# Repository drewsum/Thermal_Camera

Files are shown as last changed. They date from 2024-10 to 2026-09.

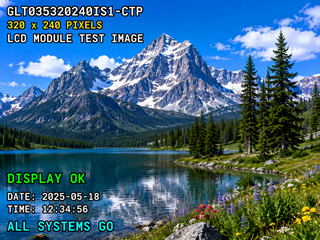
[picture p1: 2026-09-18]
rev_a/sfw/LCD_Test_Images/LCD_test_mountain.png

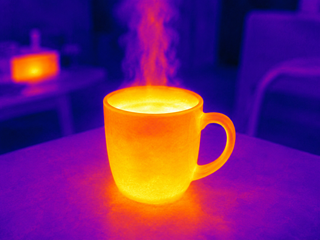
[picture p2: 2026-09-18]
rev_a/sfw/LCD_Test_Images/thermal_coffee.png

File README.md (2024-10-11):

# Thermal_Camera
DIY Thermal Camera - Drew Maatman and Michael Laffin

## Hardware:
### KiCad Project:
\Thermal_Camera\rev_a\hdw\Thermal_Camera
Made in KiCad version 8.0.5
PIC32MZ DA Grphics MCU
FLIR Lepton 3.5 Thermal Imagery Sensor
PIC32MZ DA is programmed with firmware via PICKIT4 Header (J1501)
PIC32MZ DA can be held in reset by pressing SW1501 or by inserting jumper across J1502
USB Hub can be reset by pressing SW2501
SPI FLASH can be programmed via J2002

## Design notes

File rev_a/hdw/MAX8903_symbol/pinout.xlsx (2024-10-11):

MAX8903
Pin | Name | Unit | Type | Style | Side
1 | PG | A | power_in |  | bottom
2 | PG | A | power_in |  | bottom
3 | DC | A | power_in |  | left
4 | DC | A | power_in |  | left
5 | DCM | A | input |  | left
6 | BST | A | passive |  | left
7 | IUSB | A | passive |  | left
8 | ~{DOK} | A | output | output_low | right
9 | VL | A | passive |  | right
10 | CT | A | passive |  | left
11 | IDC | A | passive |  | right
12 | GND | A | power_in |  | bottom
13 | ISET | A | passive |  | right
14 | ~{CEN} | A | input | input_low | left
15 | USUS | A | input |  | left
16 | THM | A | passive |  | right
17 | USB | A | power_in |  | left
18 | ~{FLT} | A | output | output_low | right
19 | ~{UOK} | A | output | output_low | right
20 | BAT | A | power_in |  | right
21 | BAT | A | power_in |  | right
22 | ~{CHG} | A | output | output_low | right
23 | SYS | A | power_out |  | right
24 | SYS | A | passive |  | right
25 | CS | A | passive |  | left
26 | CS | A | passive |  | left
27 | LX | A | passive |  | left
28 | LX | A | passive |  | left
29 | EP | A | power_in |  | bottom

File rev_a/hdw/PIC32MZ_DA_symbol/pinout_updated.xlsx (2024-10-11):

PIC32MZ2064DAR176
Pin | Name | Unit | Type | Style | Side
3 | AVDD | A | power_in |  | left
4 | AVDD | A | power_in |  | left
5 | AVSS | A | power_in |  | left
6 | AVSS | A | power_in |  | left
66 | DDRVREF | A | power_in |  | left
166 | VBAT | A | power_in |  | left
18 | VDDCORE | A | power_in |  | left
39 | VDDCORE | A | power_in |  | left
84 | VDDCORE | A | power_in |  | left
116 | VDDCORE | A | power_in |  | left
19 | VDDIO | A | power_in |  | left
38 | VDDIO | A | power_in |  | left
86 | VDDIO | A | power_in |  | left
102 | VDDIO | A | power_in |  | left
117 | VDDIO | A | power_in |  | left
124 | VDDIO | A | power_in |  | left
155 | VDDIO | A | power_in |  | left
156 | VDDIO | A | power_in |  | left
165 | VDDIO | A | power_in |  | left
57 | VDDR1V8 | A | power_in |  | left
58 | VDDR1V8 | A | power_in |  | left
59 | VDDR1V8 | A | power_in |  | left
60 | VDDR1V8 | A | power_in |  | left
61 | VDDR1V8 | A | power_in |  | left
62 | VDDR1V8 | A | power_in |  | left
63 | VDDR1V8 | A | power_in |  | left
67 | VDDR1V8 | A | power_in |  | left
68 | VDDR1V8 | A | power_in |  | left
72 | VDDR1V8 | A | power_in |  | left
78 | VDDR1V8 | A | power_in |  | left
21 | VSS | A | power_in |  | right
22 | VSS | A | power_in |  | right
29 | VSS | A | power_in |  | right
37 | VSS | A | power_in |  | right
48 | VSS | A | power_in |  | right
49 | VSS | A | power_in |  | right
83 | VSS | A | power_in |  | right
87 | VSS | A | power_in |  | right
94 | VSS | A | power_in |  | right
103 | VSS | A | power_in |  | right
115 | VSS | A | power_in |  | right
122 | VSS | A | power_in |  | right
123 | VSS | A | power_in |  | right
153 | VSS | A | power_in |  | right
154 | VSS | A | power_in |  | right
177 | VSS1P8 | A | power_in |  | right
44 | No Connect | A | no_connect |  | right
88 | No Connect | A | no_connect |  | right
20 | No Connect | A | no_connect |  | right
176 | No Connect | A | no_connect |  | right
85 | MCLR | A | input |  | right
45 | VBUS | A | power_in |  | right
46 | VUSB3V3 | A | power_out |  | right
47 | VUSB3V3 | A | passive |  | right
51 | D+ | A | bidirectional |  | right
50 | D- | A | bidirectional |  | right
52 | USBID | A | passive |  | right
53 | TMS/SDCD/RA0 | B | bidirectional |  | left
160 | TCK/AN24/RA1 | B | bidirectional |  | left
129 | SCL2/RA2 | B | bidirectional |  | left
128 | EBIRDY1/SDA2/RA3 | B | bidirectional |  | left
127 | GD1/EBID14/PMD14/RA4 | B | bidirectional |  | left
174 | EBIA5/AN7/PMA5/RA5 | B | bidirectional |  | left
54 | TRCLK/SDCK/SQICLK/RA6 | B | bidirectional |  | left
55 | TRD3/SDDATA3/SQID3/RA7 | B | bidirectional |  | left
1 | VREF-/CVREF-/AN27/RA9 | B | bidirectional |  | left
2 | VREF+/CVREF+/AN28/RA10 | B | bidirectional |  | left
126 | RPA14/SCL1/RA14 | B | bidirectional |  | left
125 | RPA15/SDA1/RA15 | B | bidirectional |  | left
168 | PGED1/AN0/RPB0/CTED2/RB0 | B | bidirectional |  | left
11 | PGEC1/AN9/RPB1/CTED1/RB1 | B | bidirectional |  | left
172 | AN1/C2INB/RPB2/RB2 | B | bidirectional |  | left
8 | AN8/RPB3/RB3 | B | bidirectional |  | left
175 | AN2/C1INB/RB4 | B | bidirectional |  | left
167 | AN45/RPB5/RB5 | B | bidirectional |  | left
13 | PGEC2/RPB6/RB6 | B | bidirectional |  | left
170 | PGED2/C1INA/AN46/RPB7/RB7 | B | bidirectional |  | left
10 | EBID10/AN4/RPB8/PMD10/RB8 | B | bidirectional |  | left
173 | EBIA7/AN47/HLVDIN/RPB9/PMA7/RB9 | B | bidirectional |  | left
168 | AN5/RPB10/RB10 | B | bidirectional |  | left
12 | AN49/RB11 | B | bidirectional |  | left
171 | AN6/RB12 | B | bidirectional |  | left
9 | AN48/CTPLS/RB13 | B | bidirectional |  | left
159 | AN29/SCK3/RB14 | B | bidirectional |  | left
7 | AN3/C2INA/RPB15/OCFB/RB15 | B | bidirectional |  | left
17 | EBID5/AN12/RPC1/PMD5/RC1 | B | bidirectional |  | right
14 | EBID12/AN10/RPC2/PMD12/RC2 | B | bidirectional |  | right
15 | EBIWE/AN34/RPC3/PMWR/RC3 | B | bidirectional |  | right
16 | EBIOE/AN19/RPC4/PMRD/RC4 | B | bidirectional |  | right
164 | OSC1/CLKI/RC12 | B | bidirectional |  | right
162 | SOSCI/RPC13/RC13 | B | bidirectional |  | right
161 | SOSCO/RPC14/T1CK/RC14 | B | bidirectional |  | right
163 | OSC2/CLKO/RC15 | B | bidirectional |  | right
79 | RTCC/RPD0/RD0 | B | bidirectional |  | right
73 | SCK1/RD1 | B | bidirectional |  | right
74 | GD10/EBIA14/RPD2/PMA14/PMCS1/RD2 | B | bidirectional |  | right
75 | GD11/EBIA15/RPD3/PMA15/PMCS2/RD3 | B | bidirectional |  | right
70 | SDCMD/SQICS0/RPD4/RD4 | B | bidirectional |  | right
71 | SQICS1/RPD5/RD5 | B | bidirectional |  | right
121 | ETXEN/RPD6/RD6 | B | bidirectional |  | right
120 | ETXCLK/RPD7/RD7 | B | bidirectional |  | right
76 | GD2/EBID15/RPD9/PMD15/RD9 | B | bidirectional |  | right
77 | SCK4/RD10 | B | bidirectional |  | right
119 | EMDC/RPD11/RD11 | B | bidirectional |  | right
80 | GD7/EBIA12/RPD12/PMA12/RD12 | B | bidirectional |  | right
81 | GD22/EBIA13/PMA13/RD13 | B | bidirectional |  | right
158 | AN22/RPD14/RD14 | B | bidirectional |  | right
157 | AN33/SCK6/RD15 | B | bidirectional |  | right
40 | EBID0/PMD0/RE0 | B | bidirectional |  | right
36 | EBID1/AN39/PMD1/RE1 | B | bidirectional |  | right
99 | EBID2/PMD2/RE2 | B | bidirectional |  | right
98 | EBID3/RPE3/PMD3/RE3 | B | bidirectional |  | right
43 | EBID4/AN18/PMD4/RE4 | B | bidirectional |  | right
69 | EBIA6/RPE5/PMA6/RE5 | B | bidirectional |  | right
23 | EBID6/AN16/PMD6/RE6 | B | bidirectional |  | right
24 | EBID7/AN15/PMD7/RE7 | B | bidirectional |  | right
25 | AN25/RPE8/RE8 | B | bidirectional |  | right
26 | AN26/RPE9/RE9 | B | bidirectional |  | right
91 | GD6/EBIA11/RPF0/PMA11/RF0 | C | bidirectional |  | left
90 | GD5/EBIA10/RPF1/PMA10/RF1 | C | bidirectional |  | left
41 | RPF2/SDA3/RF2 | C | bidirectional |  | left
93 | ERXERR/RPF3/RF3 | C | bidirectional |  | left
97 | GD17/EBID9/RPF4/SDA5/PMD9/RF4 | C | bidirectional |  | left
89 | GD16/EBID8/RPF5/SCL5/PMD8/RF5 | C | bidirectional |  | left
82 | RPF8/SCL3/RF8 | C | bidirectional |  | left
27 | TDO/AN31/RPF12/RF12 | C | bidirectional |  | left
28 | TDI/AN17/SCK5/RF13 | C | bidirectional |  | left
96 | GD3/EBIA8/RPG0/PMA8/RG0 | C | bidirectional |  | left
95 | GD4/EBIA9/RPG1/PMA9/RG1 | C | bidirectional |  | left
30 | AN14/C1IND/SCK2/RG6 | C | bidirectional |  | left
31 | AN13/C1INC/RPG7/SDA4/RG7 | C | bidirectional |  | left
32 | AN30/C2IND/RPG8/SCL4/RG8 | C | bidirectional |  | left
33 | EBIA2/AN23/C2INC/RPG9/PMA2/RG9 | C | bidirectional |  | left
56 | TRD1/SDDATA1/SQID1/RG12 | C | bidirectional |  | left
64 | TRD0/SDDATA0/SQID0/RG13 | C | bidirectional |  | left
65 | TRD2/SDDATA2/SQID2/RG14 | C | bidirectional |  | left
34 | AN21/RG15 | C | bidirectional |  | left
110 | ETXD2/RH0 | C | bidirectional |  | left
109 | ETXD3/RH1 | C | bidirectional |  | left
141 | SDWP/EBIRP/RH2 | C | bidirectional |  | left
140 | AN35/RH3 | C | bidirectional |  | left
35 | AN20/RH4 | C | bidirectional |  | left
100 | ERXD1/RH5 | C | bidirectional |  | left
101 | ERXD2/RH6 | C | bidirectional |  | left
139 | EBIA4/AN36/PMA4/RH7 | C | bidirectional |  | left
108 | ERXD0/RH8 | C | bidirectional |  | left
107 | ERXD3/RH9 | C | bidirectional |  | left
106 | ECOL/RH10 | C | bidirectional |  | left
138 | EBIRDY2/AN37/RH11 | C | bidirectional |  | left
105 | ECRS/RH12 | C | bidirectional |  | left
104 | ERXDV/ECRSDV/RH13 | C | bidirectional |  | left
42 | INT0/RH14 | C | bidirectional |  | left
92 | GD21/EBIA23/RH15 | C | bidirectional |  | left
118 | ETXERR/RJ0 | C | bidirectional |  | right
114 | EMDIO/RJ1 | C | bidirectional |  | right
152 | EBIRDY3/AN32/RJ2 | C | bidirectional |  | right
151 | GD20/EBIA22/RJ3 | C | bidirectional |  | right
150 | VSYNC/EBICS0/RJ4 | C | bidirectional |  | right
149 | HSYNC/EBICS1/RJ5 | C | bidirectional |  | right
148 | GCLK/EBICS2/RJ6 | C | bidirectional |  | right
147 | GEN/EBICS3/RJ7 | C | bidirectional |  | right
113 | ETXD0/RJ8 | C | bidirectional |  | right
112 | ETXD1/RJ9 | C | bidirectional |  | right
146 | GD18/EBIBS1/RJ10 | C | bidirectional |  | right
111 | ERXCLK/EREFCLK/RJ11 | C | bidirectional |  | right
145 | GD9/EBIBS0/RJ12 | C | bidirectional |  | right
144 | GD0/EBID13/PMD13/RJ13 | C | bidirectional |  | right
143 | GD8/EBID11/PMD11/RJ14 | C | bidirectional |  | right
142 | EBIA0/PMA0/RJ15 | C | bidirectional |  | right
137 | GD23/EBIA16/RK0 | C | bidirectional |  | right
136 | EBIA1/AN38/PMA1/RK1 | C | bidirectional |  | right
135 | EBIA3/AN11/PMA3/RK2 | C | bidirectional |  | right
134 | GD12/EBIA17/RK3 | C | bidirectional |  | right
133 | GD13/EBIA18/RK4 | C | bidirectional |  | right
132 | GD14/EBIA19/RK5 | C | bidirectional |  | right
131 | GD15/EBIA20/RK6 | C | bidirectional |  | right
130 | GD19/EBIA21/RK7 | C | bidirectional |  | right

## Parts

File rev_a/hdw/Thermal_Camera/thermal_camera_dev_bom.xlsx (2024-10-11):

Reference | Value | Qty | Configuration | Digi-Key PN | display_footprint
BT1401 | 18650 Cell | 1 |  | 1568-1488-ND
C201,C405,C605,C1707,C1708,C1709,C1710,C1711,C1712,C1720,C1721,C1722,C1723,C1724,C1725,C1733,C1734,C1735,C1736,C1737,C1738,C1745,C1746,C1747,C1748,C1749,C1750,C1756,C1757,C1758,C1759,C1760,C1762,C1764,C2901,C2902,C3101,C3102,C3103,C3104,C3105,C3106,C3107,C3108,C3109,C3110,C3111,C3112,C3113,C3114,C3115,C3116,C3117,C3118,C3119,C3120,C3121,C3122,C3123,C3124,C3125,C3126,C3127,C3128,C3129,C3130,C3131,C3132,C3133 | 10nF | 69 |  | 445-12201-1-ND | 402
C202,C401,C406,C601,C606,C803,C1001,C1004,C1405,C1407,C1414,C1501,C1502,C1601,C1602,C1603,C1701,C1702,C1703,C1704,C1705,C1706,C1713,C1714,C1715,C1716,C1717,C1718,C1727,C1728,C1729,C1730,C1731,C1732,C1739,C1740,C1741,C1742,C1743,C1744,C1751,C1752,C1753,C1754,C1755,C1761,C1763,C2001,C2003,C2006,C2101,C2103,C2201,C2202,C2203,C2204,C2207,C2210,C2401,C2403,C2404,C2405,C2501,C2502,C2503,C2504,C2506,C2507,C2509,C2602,C2701,C2702,C2703,C2704,C2705,C2706,C2707,C2708,C2709,C2801,C2802,C2803,C2804,C2903,C2904,C2907,C2908 | 0.1uF | 87 |  | 490-10697-1-ND | 402
C203 | 100uF | 1 |  | 718-1102-1-ND | 7343
C301,C302,C303,C501,C502,C503,C701,C702,C703,C901,C902,C903,C1101,C1102,C1103,C1301,C1302,C1303,C2305 | 0.1uF | 19 | Telemetry | 490-10697-1-ND | 402
C402,C404,C407,C408,C602,C604,C607,C608,C1201,C1203,C1204,C1402,C1404,C1409,C1410,C1412,C1413,C1765,C1766,C2102,C2104,C2607 | 10uF | 22 |  | 399-8153-1-ND | 1206
C403,C603,C801,C802,C804,C805,C1002,C1003,C1005,C1006,C1403,C1406,C1604,C1605,C2002,C2004,C2005,C2007,C2205,C2206,C2211,C2402,C2505,C2508,C2601,C2603,C2605,C2905,C2906 | 10uF | 29 |  | 490-GRM155R61A106ME11DCT-ND | 402
C1202,C1401,C1408,C1411 | 1uF | 4 |  | 311-1439-1-ND | 402
C1719,C1726,C2208,C2209 | 47pF | 4 |  | 490-5942-1-ND | 402
C2301,C2302,C2303 | 10uF | 3 | ETC | 490-GRM155R61A106ME11DCT-ND | 402
C2304 | 0.1uF | 1 | ETC | 490-10697-1-ND | 402
C2604,C2606 | 22pF | 2 |  | 490-5868-1-ND | 402
D401,D601 | BAT48JFILM | 2 |  | 497-5711-1-ND
D1201 | PMEG6010CEJ | 1 |  | 1727-3882-1-ND
D1501 | PESD3V3L5UY | 1 |  | 1727-3828-1-ND
D2001,D2002 | PESD3V3L4UF | 2 |  | 1727-5789-1-ND
D2201 | Yellow | 1 |  | VLMY1500-GS08CT-ND
D2301 | BAT48JFILM | 1 | ETC | 497-5711-1-ND
D2701,D2702,D2704,D2705,D2706,D2707,D2709,D2801 | Green | 8 |  | 1497-1219-1-ND
D2703,D2708,D2802,D2803,D2804 | Red | 5 |  | VLMS1500-GS08CT-ND
J1401 | 18650 Holder | 1 |  | BK-18650-PC2-ND
J2001 | Micro_SD_Card_Det_Hirose_DM3AT | 1 |  | HR1964CT-ND
J2101 | LCD Pixel Data | 1 |  | 2073-FFC2B35-54-GCT-ND
J2102 | LCD CTP Data | 1 |  | 2073-FFC2B35-06-GCT-ND
J2601 | USB_B_Mini | 1 |  | 732-2109-1-ND
L401,L601 | 2.2uH | 2 |  | 541-1236-1-ND | IHLP2020
L1201 | 22uH | 1 |  | 541-1243-1-ND | IHLP2020
L1401 | 4.7uH | 1 |  | 541-1222-1-ND | IHLP2020
L1501,L1502,L1601,L1602,L1701,L1702,L2401,L2501 | 600R 0.5A | 8 |  | 490-5441-1-ND
N201 | +12V 1A Power Supply | 1 |  | 993-1335-ND
N2101 | LCD Module | 1 |  | GLT035320240IS1-CTP
N2401 | Lepton3.5 Sensor | 1 |  | 500-0771-01-ND
Q401,Q601,Q1501 | BSS214NW | 3 |  | BSS214NWH6327XTSA1CT-ND
Q402,Q602 | ZXMS6004FFTA | 2 |  | ZXMS6004FFCT-ND
Q1401,Q1402 | DMN3042L | 2 |  | DMN3042L-7DICT-ND
R201 | 51.1k | 1 |  | RMCF0402FT51K1CT-ND | 402
R202,R209,R409,R807,R2605 | 1.15k | 5 |  | RMCF0402FT1K15CT-ND | 402
R203,R208 | 5.11k | 2 |  | RMCF0402FT5K11CT-ND | 402
R204,R206,R211,R402,R403,R404,R602,R603,R604,R801,R802,R1001,R1002,R1003,R1201,R1407,R1410,R1502,R1504,R1601,R1602,R1603,R1604,R1801,R1802,R2011,R2012,R2013,R2014,R2015,R2016,R2017,R2018,R2019,R2020,R2021,R2022,R2023,R2024,R2029,R2101,R2102,R2103,R2104,R2202,R2401,R2402,R2403,R2404,R2405,R2406,R2407,R2408,R2409,R2502,R2503,R2504,R2505,R2506,R2507,R2601,R2701,R2801,R2802,R2805,R2806,R2905,R2906,R2907,R2908,R2909,R2910 | 10k | 72 |  | RMCF0402FT10K0CT-ND | 402
R205,R210,R405,R407,R605,R607,R803,R805,R1004,R1006,R1204,R1206 | 10 | 12 | Telemetry | RMCF0402FT10R0CT-ND | 402
R207,R406,R606,R804,R1005,R1205,R1412,R1413 | 0.02 | 8 |  | P16010CT-ND | 612
R401,R601,R1202,R1203,R1501,R1503,R1605,R1606,R2001,R2002,R2003,R2004,R2005,R2006,R2025,R2026,R2027,R2028,R2030,R2410,R2411,R2412,R2413,R2414,R2415,R2501 | 10 | 26 |  | RMCF0402FT10R0CT-ND | 402
R408 | 3.16k | 1 |  | RMCF0402FT3K16CT-ND | 402
R608 | 1.87k | 1 |  | RMCF0402FT1K87CT-ND | 402
R609,R2606 | 1.5k | 2 |  | RMCF0402FT1K50CT-ND | 402
R806 | 2.87k | 1 |  | RMCF0402FT2K87CT-ND | 402
R1007,R1406 | 5.9k | 2 |  | RMCF0402FT5K90CT-ND | 402
R1008 | 11.8k | 1 |  | RMCF0402FT11K8CT-ND | 402
R1401,R1403 | 10K | 2 |  | RMCF0402FT10K0CT-ND | 402
R1402 | 1.8M | 1 |  | RMCF0402FT1M80CT-ND | 402
R1404,R1405,R1408,R1409 | 100k | 4 |  | RMCF0402FT100KCT-ND | 402
R1411 | 1.2k | 1 |  | RMCF0402FT1K20CT-ND | 402
R1414 | 2.2k | 1 |  | RMCF0402FT2K20CT-ND | 402
R1415 | 330 | 1 |  | RMCF0402FT330RCT-ND | 402
R1505,R2201,R2702,R2703,R2704,R2705,R2706,R2707,R2708,R2709,R2710,R2803,R2804,R2807,R2808,R2901,R2902,R2903,R2904 | 1k | 19 |  | RMCF0402FT1K00CT-ND | 402
R1701,R1702,R2203,R2204,R2602,R2603 | 27 | 6 |  | RMCF0402FT27R0CT-ND | 402
R1703,R1704,R2205,R2206 | 15k | 4 |  | RMCF0402FT15K0CT-ND | 402
R2604 | 3.57k | 1 |  | RMCF0402FT3K57CT-ND | 402
RN2101,RN2102,RN2103,RN2104 | 10k | 4 |  | Y1103CT-ND
TH1401,TH1402 | 10k | 2 |  | 445-174911-1-ND | 402
TP202,TP203,TP401,TP601,TP801,TP1001,TP1601,TP2601,TP2602 | TP | 9
U201 | TPS26600RHFT | 1 |  | 296-45478-1-ND
U301,U501,U701,U901,U1101,U1301 | INA231A | 6 | Telemetry | 296-41263-1-ND
U302,U502,U702,U902,U1102,U1302,U2302 | MCP9804 | 7 | Telemetry | MCP9804T-E/MCCT-ND
U401,U601,U1001,U1601,U2202,U2501,U2503,U2701,U2702,U2703,U2704,U2705,U2706,U2707,U2801,U2802,U2803,U2804,U2903,U2904 | 74LVC1G97 | 20 |  | 296-15582-1-ND
U402,U602 | TPS62130A | 2 |  | 296-39446-1-ND
U801,U1002,U2601 | TPS7A92 | 3 |  | TPS7A9201DSKR
U1201 | DIO5661CD6 | 1 |  | N/A
U1401 | BQ27441DRZT-G1A | 1 |  | 296-37271-1-ND
U1402 | MAX8903G | 1 |  | MAX8903GETI+-ND
U1403 | BQ29700 | 1 |  | 296-43985-1-ND
U1701 | PIC32MZ2064DAR176 | 1 |  | PIC32MZ2064DAR176-I/2J-ND
U2001 | SST25VF080B-50-4x-S2Ax | 1 |  | SST25VF080B-50-4C-S2AF-ND
U2002 | TPS22810DRV | 1 |  | 296-47868-1-ND
U2201 | FT234XD | 1 |  | 768-1178-1-ND
U2203 | FXMA108 | 1 |  | FXMA108BQX
U2301 | DS1683 | 1 | ETC | DS1683S+-ND
U2401 | FLIR_Lepton3p5_Socket | 1 |  | 1050281001
U2502 | TPS3808G33 | 1 |  | 296-17195-1-ND
U2504 | TUSB2046BIRHBT | 1 |  | 296-27130-1-ND
U2602 | TPD3S044DBVR | 1 |  | 296-38836-1-ND
U2708,U2709 | 74LVC1G97 | 2 |  | 296-15582-1-ND
U2901,U2902 | AT42QT1010-TSHR | 2 |  | AT42QT1010-TSHRCT-ND
X1601 | ECS-2520MV-240-BN | 1 |  | XC2750CT-ND
X1602 | ECS-327KE | 1 |  | XC1751CT-ND
X2401 | ECS-2520MV-250-CN | 1 |  | XC2752CT-ND
X2501 | ASE-48.000MHz | 1 |  | 535-ASE-48.000MHZ-L-C-TCT-ND

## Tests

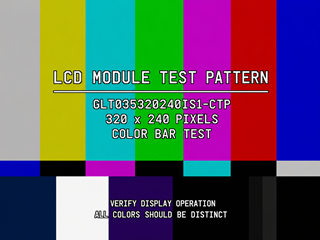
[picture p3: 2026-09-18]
rev_a/sfw/LCD_Test_Images/LCD_test.png

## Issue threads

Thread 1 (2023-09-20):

Sensor

drewsum, 2023-09-20:
https://www.digikey.com/en/products/detail/flir-lepton/500-0771-01/7606616

drewsum, 2023-09-20:
https://www.flir.com/globalassets/imported-assets/document/flir-lepton-engineering-datasheet.pdf

drewsum, 2023-09-20:
Socket: https://www.digikey.com/en/products/detail/molex/1050281001/3045223

Closed 2024-10-11.

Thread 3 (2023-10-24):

Input power + battery management

mslaffin, 2023-10-24:
### Requirements
- Accept power from several inputs
    - USB, 12V wall adapter, Li-ion battery
    - Battery probably something standard (4.2V?)
- Outputs regulated system power
- Indicate battery charge status, output supply good
- configurable to the selected battery

Some features I think are cool
-  reporting state of charge, faults, temp, etc.
- integrated buck converters
- fancy charging algos
- efficiency

Here's a few options:

[MAX8903](https://www.analog.com/media/en/technical-documentation/data-sheets/MAX8903-MAX8903Y.pdf) – Basic features shared with many parts, seems like it would work. Doesn’t require external FETs/diodes

[LTC4089-3](https://www.analog.com/media/en/technical-documentation/data-sheets/40893fa.pdf) – more configurable and could also work. More part selection. Maybe overkill.

[BQ24180](https://www.ti.com/lit/ds/symlink/bq24180.pdf?ts=1698112114656&ref_url=https%253A%252F%252Fwww.google.com%252F) - Also integrated power FETs, I2C interface

Some relevant things that need to be determined:
- [ ] #5
- [ ] #4
    - charge current
    - float voltage

Closed 2024-10-11.

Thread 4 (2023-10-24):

battery selection

mslaffin, 2023-10-24:
Some things to think about:

- Power management devices mostly limited to single cells
    - the BQ24180 also refers to "battery pack", but this may only refer to Li-polymer?
- Common characteristics for single cells
    -  3.7V nominal voltage
    - 4.2V full charge
- capacity
    - probably not more than 1-2 Ah needed
- discharge current
    - [ ] system power requirements
- integrated protection
- form factor
    - I like how DSLR-type cameras put the battery in the grip. also gun-style infrared thermometers do a similar thing
- connector type

Closed 2024-10-11.

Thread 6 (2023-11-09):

MCU selection

drewsum, 2023-11-09:
- PIC32MZ EF:
  - Pros:
    - Drew extremely familiar with this
    - Lots of code overlap with existing projects
    - Lots of pin count and memory options
    - KiCad symbols ready to go
    - Hand solderable packages
    - The compiler and IDE are awesome, no need to bit shift to control registers
    - Easy debug
    - Extremely flexible interrupts
  - Cons:
    - Memory for graphics is limited
    - No built in LCD controller (would need to leverage other peripherals not meant for this)
    - Unsure how USB would work (I just normally use a UART to USB bridge)
    - No built in SD card controller
    - MPLAB Harmony code framework is garbage (could generate peripheral drivers and copy to bare metal project)
- PIC32MZ DA:
  - Pros:
    - Meant for graphics applications
    - More internal SRAM available than 32MZ EF
    - Built in LCD controller
    - Built in on-die 32MB DDR2
    - Certain options support 128MB external DDR2
    - Very similar to PIC32MZ EF
    - Built in SD card controller
    - The compiler and IDE are awesome, no need to bit shift to control registers
    - Apparently there is a GUI for configuring the graphics capabilities
    - Available in hand solderable packages, also BGA
    - Dedicated GPU
    - Easy debug
    - Extremely flexible interrupts
    - Its cool af
  - Cons:
    - New part to both of us
    - Some code overlap with 32MZ EF, might be able to branch off easily though, but this would require lots of new code
    - Would need new KiCad symbols
    - Would need lots of support circuit design thought/analysis/critical thinking, not just copy and paste
    - Unsure how useful the graphics configuration applications actually are, they could be hot steaming garbage and we'd be on our own
- STM32:
  - Pros:
    - It's a thing that exists and apparently the support is good
    - I have seen that they have some kind of graphics support
  - Cons:
    - I have no idea how to use these
- ESP32 S3:

drewsum, 2023-11-10:
I had chatted with Michael a bunch about this, and the PIC32MZ DA seems like a good fit. This will require a lot of investment in code and hardware development, but since it's meant for video, it seems like a good idea.

There are a few different flavors of PIC32MZ DA, but the more modern SKUs from circa 2019 have a datasheet here: https://ww1.microchip.com/downloads/aemDocuments/documents/MCU32/ProductDocuments/DataSheets/PIC32MZ-Graphics-%28DAK-DAL-DAR-DAS%29-Family-Datasheet-DS60001565D.pdf

They offer them in BGA and LQFP packages in high pin counts. I looked into the BGA package in KiCad briefly and it looks like the ball pitch is barely too tight to make work with JLCPCB design rules. I think it would be easier to use the LQFP package, but would take up much more space.

Looking at the SKUs for this package, these are available:
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

I think the PIC32MZ2064DAR176 is most realistic. The high internal SRAM is nice, as is the internal 32MB DDR2, which we'd use as a frame buffer for the LCD. We could also try to get fancy with microchip's GUI generation tools.

This is enough of a departure from my current projects to make this interesting and require engineering and firmware rigor, but is close enough where a lot of code could be ported over easily.

PIC32MZ2064DAR176  appears to be available in ok-ish quantities according to octopart. If we design a PCB around this, the good news is that there are other options that are drop in replacements, just with different memory sizes. So I think that the part selection is actually quite flexible.

Closed 2024-10-11.

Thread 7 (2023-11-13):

Consider +3.0V supply instead of +3.3V supply

drewsum, 2023-11-13:
PIC32MZ DA supports a +3.0V VDDIO, and the FLIR lepton is limited to +3.0V IO. Consider consolidating these instead of having two supplies

drewsum, 2023-11-14:
I don't think we'll be able to swing this based on just how much on this board already needs +3.3V... most LCDs I'm seeing need +3.3V, the oscillators I'm already comfortable with are +3.3V only, USH hub, etc. So I'm going to close this for now

drewsum, 2023-11-15:
Things that would need to move from +3.3V to +3.0V in order to make this work:

- PIC IO (doable)
- Telemetry circuits (INA219 has min VIN +3.0V, MCP9804 ok)
- TPS62130 does not come in a fixed +3.0V option, could use feedback resistors
- Check to see if PIC KIT 4 is compatible with +3.0V
- PIC oscillators (current part is +3.3V only, oscillator I found for FLIR sensor is +3.0V compatible)
- SD card
- SPI Flash
- SQI Flash
- LCD (most options I'm seeing out there are +3.3V only)
- USB UART level shifter/voltage domain isolator
- DS1683 (this should be ok)
- All LVC logic gates (should be ok, maybe move to AUP family?)

There is a lot here, but it's not impossible. I think the main deciding factor is if we can find a usable +3.0V IO-compatible TFT LCD screen.

According to the SD card spec, you can power micro SD cards with as low as 2.7V: https://www.sdcard.org/developers/sd-standard-overview/

drewsum, 2023-11-18:
I decided that based on what I've seen for LCDs, and the availability of parts that are indeed +3.0V VDD tolerant, we should do this.

Closed 2024-10-11.

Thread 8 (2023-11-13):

Consider USB hub for multiple USB upstream facing ports

drewsum, 2023-11-13:

drewsum, 2023-11-15:
The idea here would be to use a USB 2 port hub to break out both the USB UART debug port and the USB HS mass storage port (what would allow us to easily move captured thermal images to a host PC) through a single USB connector. The hub would enumerate as a generic hub and expose both the FTDI UART device and the PIC32MZ DA HS USB port like any other device.

The idea would be that the hub IC would be powered by VBUS, and could remain unpowered when a USB connector is not connected (I think?). There may be complications with this due to DC leakage paths from the PIC to the unpowered hub IC.

An alternative would be to just use two USB connectors, which I'm also ok with

Closed 2024-10-11.

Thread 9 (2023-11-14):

User Interface Ideas

drewsum, 2023-11-14:
- Try to support cap touch screen on LCD for extended options
- Have a capacitive pushbutton for power button, and "save frame", as a minimum fallback

Closed 2024-10-11.

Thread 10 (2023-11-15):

LCD

drewsum, 2023-11-15:
https://www.digikey.com/en/products/detail/globaltech-display/GLT035320240IS1-CTP/16588709

drewsum, 2023-11-15:
- Needs to support at least the resolution of the Lepton3.5 sensor (i dont remember what this is)
- Would be nice to match the aspect ratio of the sensor but not required since we can scale the video frames
- Would be nice to have it a decent size but not huge
- Cap touch screen maybe? Lets talk about user interface in another gitlab issue, i have ideas
- Should match one of the IO types that the PIC32MZ DA GLCD controller can output, I'm unsure of the options but it should be captured in the datasheet, also see the PIC32 GLCD "reference manual" doc (WVGA? idk what any of these are or what they mean)
- RGB888 data format (PIC32 GLCD controller does 24 bit color)
- Match IO voltage level of PIC (+3.3V or +3.0V)
- Preferably not super expensive

drewsum, 2023-11-16:
This seems like a thing a person could use to drive the LED backlight to an LCD, it seems to be made to run off a lithium battery, it's super small, looks like it supports PWM dimming (although I've had mixed luck with these kinds of claims in the past), and has a symbol in KiCad laready

https://www.analog.com/media/en/technical-documentation/data-sheets/3465fa.pdf

drewsum, 2023-11-21:
> https://www.digikey.com/en/products/detail/globaltech-display/GLT035320240IS1-CTP/16588709

This went out of stock and doesnt seem to have much availability anywhere else.

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

drewsum, 2024-07-18:
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

Back in stock, and this FFC connector could probably work:
https://www.digikey.com/en/products/detail/kyocera-avx/046240054005800/1279146

Closed 2024-10-11.

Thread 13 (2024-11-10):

Rev A ECOs

drewsum, 2024-11-10:
- POS3P0_RUN is hardwired to POS12_PGOOD. If POS12 is not present, POS3P0 will not be up. This means that when switching to battery power, POS3P0 will not stay up. For now, remove R401 and modwire POS3P0 to VCOM

drewsum, 2024-11-15:
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

USB 15k D+/D- pulldowns were placed on the wrong side of the 27 ohm resistors

drewsum, 2024-12-06:
USB hub issues:
Try:

- Cutting RTS/CTS signals from FTDI to octal buffer
- removing filter caps on D+/D- at FTDI

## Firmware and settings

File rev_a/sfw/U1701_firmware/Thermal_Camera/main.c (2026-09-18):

/* 
 * File:   main.c
 * Author: drewm
 *
 */

#include <xc.h>
#include <stdio.h>
#include <stdbool.h>
#include <string.h>

// Core Drivers
#include "core/pic32mzda_configuration.h"
#include "core/device_control.h"
#include "core/32mzda_interrupt_control.h"
#include "core/heartbeat_timer.h"
#include "core/watchdog_timer.h"
#include "core/prefetch.h"
#include "core/cause_of_reset.h"
#include "core/rtcc.h"
#include "core/hlvd.h"
#include "core/ddr2.h"

// SPI
#include "spi/spi3.h"
#include "spi/device_driver/w25q128jv.h"
#include "spi/device_driver/w25q128jv_disk.h"
#include "spi/flash_fileio.h"

// SDHC / microSD
#include "sdhc/sdhc.h"
#include "sdhc/device_driver/sd_card.h"
#include "sdhc/sd_fileio.h"

// USB (mass storage device)
#include "usb/usb.h"
#include "usb/device_driver/usb_msd.h"

// GLCD
#include "glcd/glcd.h"

// GUI (LVGL on GLCD Layer 1)
#include "gui/gui.h"

// FLIR Lepton 3.5 thermal camera (VoSPI on SPI4, CCI on I2C1)
#include "application/flir/flir.h"
#include "application/flir/flir_vospi.h"
#include "application/flir/flir_process.h"

// GPIO
#include "gpio/pin_macros.h"
#include "gpio/pic32mzda_gpio_setup.h"


//
//// Application
#include "application/error_handler.h"
#include "application/main.h"
#include "application/power_saving.h"
#include "application/heartbeat_services.h"
#include "application/telemetry.h"
#include "application/pgood_monitor.h"
#include "application/pushbuttons.h"
#include "application/backlight_pwm.h"
#include "application/image_loader.h"
#include "application/still_capture.h"


////// I2C
#include "i2c/i2c_master.h"
#include "i2c/i2c_devices.h"
//// USB UART
#include "usb_uart/terminal_control.h"
#include "usb_uart/uthash.h"
#include "usb_uart/usb_uart.h"
#include "usb_uart/usb_uart_rx_lookup_table.h"
//
////// ADC
#include "adc/adc.h"
#include "application/adc_channels.h"


// Prints a boot initialization result line and records failures. On success it
// prints "    <label> Initialized" in green; on failure it prints
// "    <label> FAILED to initialize" in bold red and sets *error_flag (pass
// NULL for subsystems with no dedicated init flag). Returns ok unchanged so it
// can wrap an init call inline. Leaves the terminal in green/normal afterward.
static bool reportInit(const char *label, bool ok, volatile uint8_t *error_flag) {

    if (ok) {

        terminalTextAttributes(GREEN_COLOR, BLACK_COLOR, NORMAL_FONT);
        printf("    %s Initialized\r\n", label);

    }

    else {

        if (error_flag != NULL) *error_flag = 1;
        terminalTextAttributes(RED_COLOR, BLACK_COLOR, BOLD_FONT);
        printf("    %s FAILED to initialize\r\n", label);
        terminalTextAttributes(GREEN_COLOR, BLACK_COLOR, NORMAL_FONT);

    }

    return ok;

}

void main(void) {

    
    // Save the cause of the most recent device reset
    // This also checks for configuration errors
    reset_cause = getResetCause();
    
    // Clear the terminal
    terminalClearScreen();
    terminalSetCursorHome();
    
    // set serial terminal window name
    char *terminal_title_str;
    terminal_title_str = (char *) malloc(64);
    sprintf(terminal_title_str, "%s Serial Terminal", PROJECT_NAME_STR);
    terminalSetTitle(terminal_title_str);
    free(terminal_title_str);
    
    terminalTextAttributesReset();
    terminalTextAttributes(GREEN_COLOR, BLACK_COLOR, BOLD_FONT);
    printf("%s\r\n", PROJECT_NAME_STR);
    printf("Host Firmware Version: %s, Platform Hardware Revision: %s\r\n", FIRMWARE_VERSION_STR, PLATFORM_REVISION_STR);
    printf("Created by Drew Maatman, %s\r\n", PROJECT_DATE_STR);
    
    printf("\r\n");
    
    printf(""
    "\r\n"        
    "  _____ _                               _    ____                               \r\n"
    " |_   _| |__   ___ _ __ _ __ ___   __ _| |  / ___|__ _ _ __ ___   ___ _ __ __ _ \r\n"
    "   | | | '_ \\ / _ \\ '__| '_ ` _ \\ / _` | | | |   / _` | '_ ` _ \\ / _ \\ '__/ _` |\r\n"
    "   | | | | | |  __/ |  | | | | | | (_| | | | |__| (_| | | | | | |  __/ | | (_| |\r\n"
    "   |_| |_| |_|\\___|_|  |_| |_| |_|\\__,_|_|  \\____\\__,_|_| |_| |_|\\___|_|  \\__,_|\r\n"
    "               \r\n");

    terminalTextAttributesReset();
    
     // Print cause of reset
    if (    reset_cause == Undefined ||
            reset_cause == Primary_Config_Registers_Error ||
            reset_cause == Primary_Secondary_Config_Registers_Error ||
            reset_cause == Config_Mismatch ||
            reset_cause == DMT_Reset ||
            reset_cause == WDT_Reset ||
            reset_cause == Software_Reset ||
            reset_cause == External_Reset ||
            reset_cause == BOR_Reset ||
            reset_cause == VBAT_POR) {

        terminalTextAttributes(RED_COLOR, BLACK_COLOR, NORMAL_FONT);

    }

    else {

        // Deep_Sleep_Reset and VBAT_Wake are expected outcomes of the
        // low-power features this device is configured for, not faults
        terminalTextAttributes(GREEN_COLOR, BLACK_COLOR, NORMAL_FONT);

    }

    // Deep Sleep exit, VBAT wake, and VBAT POR all re-arm a POR at the
    // hardware level (RAM/SFRs reset the same as a plain POR), so persistent
    // error flags are just as unreliable after these as after a plain POR
    if (    reset_cause == POR_Reset ||
            reset_cause == Deep_Sleep_Reset ||
            reset_cause == VBAT_Wake ||
            reset_cause == VBAT_POR) {
        clearErrorHandler();
        live_telemetry_enable = 0;
    }

    errorHandlerInitialize();

    // live_telemetry_print_request is not persistent, so always clear it at boot
    live_telemetry_print_request = 0;

    printf("\r\nCause of most recent device reset: %s\r\n\r\n", getResetCauseString(reset_cause));
    terminalTextAttributesReset();
    
    terminalTextAttributes(GREEN_COLOR, BLACK_COLOR, BOLD_FONT);
    printf("Beginning Host Initialization:\r\n");
    terminalTextAttributes(GREEN_COLOR, BLACK_COLOR, NORMAL_FONT);
    
     // setup GPIO pins
    reportInit("GPIO Pins", gpioInitialize(), NULL);

    // block on POS3P0 and POS1P8 power stability
    while(POS3P0_PGOOD_PIN == LOW);
    while(POS1P8_PGOOD_PIN == LOW);
    printf("    Input power is stable\r\n");
    
    // Disable global interrupts so clocks can be initialized properly
    disableGlobalInterrupts();
    
    // Initialize system clocks
    reportInit("Oscillators, PLL, and System Clocks", clockInitialize(),
            &error_handler.flags.clock_init_error);
        
    // Enable Global Interrupts
    bool interrupts_ok = interruptControllerInitialize();
    enableGlobalInterrupts();
    reportInit("Interrupt Controller", interrupts_ok, NULL);
    
    // Setup error handling
    reportInit("Error Handler", errorHandlerInitialize(), NULL);

    // Setup Power/Shutter pushbutton change-notification interrupts
    reportInit("Pushbuttons", pushbuttonsInitialize(), NULL);

    // Setup heartbeat timer
    reportInit("Heartbeat Timer", heartbeatTimerInitialize(),
            &error_handler.flags.heartbeat_timer_init_error);
        
    // Setup USB UART debugging
    reportInit("USB UART", usbUartInitialize(),
            &error_handler.flags.usb_uart_init_error);
    
    // Setup prefetch module
    reportInit("CPU Instruction Prefetch Module", prefetchInitialize(),
            &error_handler.flags.prefetch_init_error);
    while(usbUartCheckIfBusy());
    
    // Disable unused peripherals for power savings
    reportInit("Peripheral Module Disable (PMD)", PMDInitialize(),
            &error_handler.flags.pmd_init_error);
    while(usbUartCheckIfBusy());

    // setup watchdog timer
    reportInit("Watchdog Timer", watchdogTimerInitialize(),
            &error_handler.flags.watchdog_init_error);
    while(usbUartCheckIfBusy());
    
    // ---- Splash-screen fast path ------------------------------------------
    // Everything from here to the backlight enable below is exactly the
    // dependency chain the splash needs, and nothing else: DDR2 (frame
    // buffers + LVGL heap), the SPI flash and its FAT volume (where
    // SPLASH.PNG lives), the GLCD and its Layer 2, the backlight, LVGL
    // (whose heap lodepng decodes into), and the I2C bus master -- the last
    // of these only because lighting the backlight is now conditional on the
    // GT911 touch controller answering, i.e. on the panel being populated.
    // The bus master is register setup only; the one real cost is the GT911
    // probe itself (~70ms of datasheet-mandated reset timing), which is
    // documented at the call site.
    //
    // The RTCC, ADC, I2C *device* probe, SDHC controller and USB device
    // stack all used to run in here; none of them is needed to put a picture
    // on the panel, and together with their console output they were pushing
    // the splash several hundred milliseconds later than necessary. They now
    // run immediately AFTER the splash is lit -- see "deferred bring-up"
    // below. Anything added here in future should be able to justify itself
    // as a splash dependency.

    // Power the FLIR Lepton up BEFORE the I2C bus is touched. This is not
    // optional: with its +2.8V/+1.2V rails down, the unpowered module clamps
    // SDA/SCL low through its I/O structures and every other device on I2C1
    // (temp sensors, power monitors, fuel gauge, touch controller) becomes
    // unreachable. So the sensor is powered for the whole run -- only the
    // video stream is on demand ("FLIR Stream On").
    //
    // This call is the fast part of the sequence (rails -> PGOOD -> master
    // clock -> release power-down -> release reset); the camera's ~950ms boot
    // then overlaps everything below and is collected by FLIR_WaitUntilReady()
    // once I2C and the display are up. Failures latch flir_* error flags.
    reportInit("FLIR Lepton Power", FLIR_PowerOn(), NULL);
    while(usbUartCheckIfBusy());

    // Initialize the 32MB DDR2 SDRAM stacked in this device's package
    reportInit("DDR2 SDRAM Controller", ddr2Initialize(),
            &error_handler.flags.ddr2_init_error);
    while(usbUartCheckIfBusy());

    // Initialize the W25Q128JV SPI NOR flash on SPI3
    reportInit("SPI Flash (W25Q128JV)", W25Q128JV_Initialize(),
            &error_handler.flags.spi_flash_init_error);
    while(usbUartCheckIfBusy());

    // FAT volume "1:" on the SPI flash (512B-sector disk layer over the
    // 4KB-erase part, then mount -- formats on first boot, so the
    // "formatting..." notice is expected exactly once per blank part).
    // SPLASH.PNG is read from this volume, so it is on the fast path.
    reportInit("SPI Flash Filesystem",
            W25Q128JV_Disk_Initialize() && FlashFileIO_MountAndFormatIfNeeded(),
            &error_handler.flags.flash_fs_init_error);
    while(usbUartCheckIfBusy());

    // Bring up the Graphics LCD Controller for the on-board
    // GLT035320240IS1-CTP panel: programs timing/Layer 0 from a blank
    // (zeroed) frame buffer in DDR2 and drives the panel reset sequence.
    // The frame buffer is intentionally left blank -- filling it with
    // actual image data is a separate step. Must come after ddr2Initialize()
    // above (the frame buffer lives in DDR2).
    reportInit("Graphics LCD Controller", GLCD_Initialize(),
            &error_handler.flags.glcd_init_error);
    while(usbUartCheckIfBusy());

    // GLCD Layer 2 (on-demand still-image layer): brought up as early as the
    // hardware allows -- right after GLCD_Initialize(), ahead of the GUI and
    // the Lepton -- so the splash screen below can go up before either of
    // those slower subsystems is ready. Only needs the controller running
    // (glcd.c checks LCDEN itself); it does NOT need GUI_Initialize(), which
    // is why this sits here rather than next to ImageLoader_DisplayPNG().
    reportInit("GLCD Layer 2 (still image)", GLCD_Layer2Initialize(), NULL);
    while(usbUartCheckIfBusy());

    // Backlight brightness is PWM-driven (OC3/Timer4, application/backlight_pwm.c)
    // rather than a plain digital enable pin -- must be initialized after
    // clockInitialize() above (which sets CFGCON.OCACLK=1 under unlock,
    // establishing the OC3-to-Timer4 pairing this driver verifies at init;
    // see backlight_pwm.h for the full story).
    reportInit("Backlight PWM", BacklightPWM_Initialize(),
            &error_handler.flags.backlight_pwm_init_error);
    while(usbUartCheckIfBusy());

    // setup I2C -- still after FLIR_PowerOn() above, which is the constraint
    // that actually matters (an unpowered Lepton clamps SDA/SCL low).
    //
    // This is on the splash fast path only because the backlight is now
    // gated on the GT911 touch controller answering (see the CTP probe
    // below): the bus master has to be up before that probe can run. It is
    // just register setup -- no bus traffic, no measurable time -- so it
    // costs the splash nothing. The 15-device probe it used to be paired
    // with stays deferred, down in "deferred bring-up".
    reportInit("I2C Bus Master", I2C_Initialize(),
            &error_handler.flags.i2c_init_error);
    while(usbUartCheckIfBusy());

    // Bring up LVGL on GLCD Layer 1: a transparent GUI overlay the
    // controller alpha-blends over the Layer 0 image. Must come after
    // GLCD_Initialize() (it enables a layer on the running controller) and
    // after ddr2Initialize() (its two overlay buffers and its 4MB heap are
    // all in DDR2). That heap also backs every PNG decode
    // (application/image_loader.c), so this has to run before the
    // "Display Image:" command can be used.
    reportInit("Graphics User Interface", GUI_Initialize(),
            &error_handler.flags.gui_init_error);
    while(usbUartCheckIfBusy());

    // Display the splash screen now: Layer 2 has been enabled since right
    // after GLCD_Initialize() above, and this is the earliest point the PNG
    // decode itself can run, since it allocates from the LVGL heap that
    // GUI_Initialize() just handed out (application/image_loader.h). Layer 2
    // is fully opaque and painted on top of Layer 0/1, so it hides the (still
    // booting) Lepton and the just-built GUI screens until the splash timer
    // below dismisses it.
    ImageLoader_DisplayPNG(IMAGE_MEDIA_SPI_FLASH, "SPLASH.PNG");

    // Light the panel THE MOMENT the splash is in the frame buffer, and not
    // one line of init sooner or later.
    //
    // BacklightPWM_Initialize() above only programs the OC3/Timer4 PWM; it
    // leaves the duty cycle at 0, i.e. the backlight physically OFF. This
    // SetBrightness() call used to sit after the whole FLIR bring-up and the
    // SD card mount, so the panel stayed dark for that entire stretch even
    // though the splash pixels had been sitting in the Layer 2 buffer the
    // whole time -- and once FLIR_WaitUntilReady() grew a multi-second poll
    // window (application/flir/flir.c), a camera that was slow to answer
    // held the screen black for seconds. THAT was the "splash takes ages to
    // appear" delay; the panel was lit last instead of first.
    //
    // Everything below this line is therefore invisible to the user: the
    // splash is already up and covering Layer 0/1 while it runs.
    //
    // The backlight is gated on the panel's integrated GT911 capacitive
    // touch controller answering on I2C: its ACK is a reliable proxy for
    // "the LCD module is actually populated on this board", which the GLCD
    // Controller itself cannot detect (it only configures MCU-internal
    // registers, so it comes up perfectly happy driving nothing).
    //
    // The probe is the ONE thing allowed to delay the splash: it costs
    // ~70ms, almost all of it the GT911's mandated power-up reset/
    // address-select timing (10ms + 5ms + 50ms of pin toggling, see
    // i2c/device_driver/gt911.h), which cannot be shortened. That buys the
    // panel-presence check; the alternative was gating on the full 15-device
    // probe several hundred milliseconds further down. The rest of that
    // probe stays deferred -- only the CTP is pulled forward here, and
    // I2CDevices_Initialize() below re-probes it harmlessly along with
    // everything else.
    //
    // No error_handler flag is passed to reportInit(): like the "I2C Devices"
    // probe below, I2CDevices_InitializeOne() has already latched this
    // device's OWN flag (I2C_DEV_CTP_1_i2c_error or _config_error, generated
    // from I2C_DEVICE_LIST -- see error_handler.h), which is more specific
    // than any single aggregate flag would be.
    if (reportInit("LCD Touch Controller (GT911)",
            I2CDevices_InitializeOne(I2C_DEV_CTP_1), NULL)) {
        BacklightPWM_SetBrightness(100);
        terminalTextAttributes(GREEN_COLOR, BLACK_COLOR, NORMAL_FONT);
        printf("    LCD Backlight Enabled (touch controller present)\r\n");
    } else {
        terminalTextAttributes(RED_COLOR, BLACK_COLOR, NORMAL_FONT);
        printf("    LCD Backlight left OFF (touch controller not detected)\r\n");
    }
    terminalTextAttributesReset();
    while(usbUartCheckIfBusy());

    // Non-blocking splash-screen dismiss timer, checked once per superloop
    // pass (see splash_screen_pending below) instead of a blocking
    // softwareDelay() (core/device_control.c -- a raw NOP-counting loop with
    // no time calibration), which used to stall I2C/USB/GUI/FLIR servicing
    // for its whole duration. GUI_GetTickMs() (gui/gui.c) is the same
    // monotonic since-boot millisecond source LVGL's own tick already uses,
    // so no second clock is introduced.
    //
    // The clock starts HERE rather than at the top of boot, so the splash
    // gets its full display time no matter how long the deferred bring-up
    // below takes.
    #define SPLASH_SCREEN_DISPLAY_MS   6000u   // tune to taste
    uint32_t splash_screen_shown_tick_ms = GUI_GetTickMs();
    bool splash_screen_pending = true;

    // ---- Deferred bring-up ------------------------------------------------
    // Everything the splash does NOT depend on, moved below it so none of it
    // sits between power-on and a lit panel. Ordering constraints that still
    // apply within this block: the device probe must precede the battery
    // read; SDHC_Initialize() must precede the card mount further down.
    // (I2C_Initialize() used to head this block; it moved up into the fast
    // path when the backlight became conditional on the CTP probe.)

    bool rtcc_ok = rtccInitialize();
    // Deep_Sleep_Reset and VBAT_Wake keep the RTCC running across the event
    // specifically so its time doesn't need to be cleared here -- only clear
    // it when the time was never reliably set (POR) or the backup battery
    // that was supposed to maintain it is missing/depleted (VBAT_POR)
    if (reset_cause == POR_Reset || reset_cause == VBAT_POR) rtccClear();
    reportInit("Real Time Clock-Calendar", rtcc_ok,
            &error_handler.flags.rtcc_init_error);
    while(usbUartCheckIfBusy());

    // Enable ADC
    reportInit("Analog to Digital Converter", ADCInitialize(),
            &error_handler.flags.adc_init_error);
    while(usbUartCheckIfBusy());

    // setup HLVD
    bool hlvd_ok = hlvdInitialize(5, HLVD_DIRECTION_LOW_VOLTAGE);
    while(!hlvdIsReady());
    reportInit("HLVD", hlvd_ok && hlvdIsReady(),
            &error_handler.flags.hlvd_init_error);
    while(usbUartCheckIfBusy());

    // Bring up the SDHC peripheral itself (clocks/interrupt/register
    // defaults only, no card interaction) -- must succeed regardless of
    // whether a card happens to be inserted. Card detection + mount happens
    // later still, after the FLIR bring-up; see that call site.
    reportInit("SDHC Controller", SDHC_Initialize(),
            &error_handler.flags.sdhc_init_error);
    while(usbUartCheckIfBusy());

    // USB mass storage device (native USBHS module to the on-board hub):
    // exposes the SD card (LUN 0) and SPI flash (LUN 1) as two removable
    // drives to a USB host. Requires PMDInitialize() above to have left
    // the USB module enabled.
    reportInit("USB Mass Storage Device", USB_Initialize(),
            &error_handler.flags.usb_msd_init_error);
    while(usbUartCheckIfBusy());

    // probe every device in I2C_DEVICE_LIST (7x MCP9804 temp sensors + 6x
    // INA231A power monitors); I2CDevices_Initialize() records each device's
    // own pass/fail into error_handler.flags.<I2C_DEVICE_ID>_i2c_error (the
    // same flag its runtime reads later latch into on a NACK/timeout), so no
    // single aggregate flag is passed here.
    //
    // Note: with no battery installed this reports failure, because the
    // BQ27441 fuel gauge is powered from the cell -- an expected outcome on
    // a bench board running from USB, not a bus fault.
    reportInit("I2C Devices", I2CDevices_Initialize(), NULL);
    while(usbUartCheckIfBusy());
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

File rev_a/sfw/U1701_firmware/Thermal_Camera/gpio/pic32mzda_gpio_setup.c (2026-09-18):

#include <xc.h>
#include <stdio.h>
#include <string.h>

#include "gpio/pic32mzda_gpio_setup.h"
#include "usb_uart/terminal_control.h"

// initializes port A GPIO pins
void portAGPIOInitialize (void) {
    
    gpioPinSetup(gpio_port_a, 0, TRIS_INPUT, LAT_LOW, ODC_DISABLE, ANALOG_DISABLE);
    gpioPinSetup(gpio_port_a, 1, TRIS_OUTPUT, LAT_LOW, ODC_DISABLE, ANALOG_DISABLE);
    gpioPinSetup(gpio_port_a, 2, TRIS_INPUT, LAT_LOW, ODC_DISABLE, ANALOG_DISABLE);
    gpioPinSetup(gpio_port_a, 3, TRIS_OUTPUT, LAT_LOW, ODC_DISABLE, ANALOG_DISABLE);
    gpioPinSetup(gpio_port_a, 4, TRIS_OUTPUT, LAT_LOW, ODC_DISABLE, ANALOG_DISABLE);
    gpioPinSetup(gpio_port_a, 5, TRIS_OUTPUT, LAT_LOW, ODC_DISABLE, ANALOG_DISABLE);
    gpioPinSetup(gpio_port_a, 6, TRIS_INPUT, LAT_LOW, ODC_DISABLE, ANALOG_DISABLE);
    gpioPinSetup(gpio_port_a, 7, TRIS_INPUT, LAT_LOW, ODC_DISABLE, ANALOG_DISABLE);
    gpioPinSetup(gpio_port_a, 9, TRIS_INPUT, LAT_LOW, ODC_DISABLE, ANALOG_DISABLE);
    gpioPinSetup(gpio_port_a, 10, TRIS_INPUT, LAT_LOW, ODC_DISABLE, ANALOG_DISABLE);
    gpioPinSetup(gpio_port_a, 14, TRIS_INPUT, LAT_LOW, ODC_DISABLE, ANALOG_DISABLE);
    gpioPinSetup(gpio_port_a, 15, TRIS_INPUT, LAT_LOW, ODC_DISABLE, ANALOG_DISABLE);
    
}

// initializes port B GPIO pins
void portBGPIOInitialize (void) {

    gpioPinSetup(gpio_port_b, 0, TRIS_OUTPUT, LAT_LOW, ODC_DISABLE, ANALOG_DISABLE);
    gpioPinSetup(gpio_port_b, 1, TRIS_OUTPUT, LAT_LOW, ODC_DISABLE, ANALOG_DISABLE);
    gpioPinSetup(gpio_port_b, 2, TRIS_OUTPUT, LAT_HIGH, ODC_DISABLE, ANALOG_DISABLE);
    gpioPinSetup(gpio_port_b, 3, TRIS_OUTPUT, LAT_HIGH, ODC_DISABLE, ANALOG_DISABLE);
    RPB3Rbits.RPB3R = U5TX_PPS_OUTPUT;                                                  // Assign RPB3 as U5TX
    gpioPinSetup(gpio_port_b, 4, TRIS_OUTPUT, LAT_HIGH, ODC_DISABLE, ANALOG_DISABLE);
    gpioPinSetup(gpio_port_b, 5, TRIS_OUTPUT, LAT_LOW, ODC_DISABLE, ANALOG_DISABLE);
    RPB5Rbits.RPB5R = OC3_PPS_OUTPUT;                                                   // Assign RPB5 as OC3
    gpioPinSetup(gpio_port_b, 6, TRIS_INPUT, LAT_LOW, ODC_DISABLE, ANALOG_DISABLE);
    U4RXRbits.U4RXR = RPB6_PPS_INPUT;                                                   // Assign RPB6 as U4RX (USB UART receiver)
    gpioPinSetup(gpio_port_b, 7, TRIS_INPUT, LAT_LOW, ODC_DISABLE, ANALOG_DISABLE);
    gpioPinSetup(gpio_port_b, 8, TRIS_INPUT, LAT_LOW, ODC_DISABLE, ANALOG_DISABLE);
    gpioPinSetup(gpio_port_b, 9, TRIS_OUTPUT, LAT_HIGH, ODC_DISABLE, ANALOG_DISABLE);
    RPB9Rbits.RPB9R = SDO3_PPS_OUTPUT;                                                  // Assign RPB9 as SDO3
    gpioPinSetup(gpio_port_b, 10, TRIS_INPUT, LAT_LOW, ODC_DISABLE, ANALOG_DISABLE);
    SDI3Rbits.SDI3R = RPB10_PPS_INPUT;                                                  // Assign RPB10 as SDI3
    gpioPinSetup(gpio_port_b, 11, TRIS_OUTPUT, LAT_LOW, ODC_DISABLE, ANALOG_DISABLE);
    gpioPinSetup(gpio_port_b, 12, TRIS_OUTPUT, LAT_HIGH, ODC_DISABLE, ANALOG_DISABLE);
    gpioPinSetup(gpio_port_b, 13, TRIS_OUTPUT, LAT_LOW, ODC_DISABLE, ANALOG_DISABLE);
    gpioPinSetup(gpio_port_b, 14, TRIS_OUTPUT, LAT_HIGH, ODC_DISABLE, ANALOG_DISABLE);
    gpioPinSetup(gpio_port_b, 15, TRIS_OUTPUT, LAT_LOW, ODC_DISABLE, ANALOG_DISABLE);

}

// initializes port C GPIO pins
void portCGPIOInitialize (void) {

    gpioPinSetup(gpio_port_c, 1, TRIS_INPUT, LAT_LOW, ODC_DISABLE, ANALOG_DISABLE);
    gpioPinSetup(gpio_port_c, 2, TRIS_INPUT, LAT_LOW, ODC_DISABLE, ANALOG_DISABLE);
    gpioPinSetup(gpio_port_c, 3, TRIS_INPUT, LAT_LOW, ODC_DISABLE, ANALOG_DISABLE);
    gpioPinSetup(gpio_port_c, 4, TRIS_OUTPUT, LAT_LOW, ODC_DISABLE, ANALOG_DISABLE);
    RPC4Rbits.RPC4R = OC4_PPS_OUTPUT;                                                   // Assign RPC4 as OC4
    gpioPinSetup(gpio_port_c, 12, TRIS_INPUT, LAT_LOW, ODC_DISABLE, ANALOG_DISABLE);
    gpioPinSetup(gpio_port_c, 13, TRIS_OUTPUT, LAT_LOW, ODC_DISABLE, ANALOG_DISABLE);
    gpioPinSetup(gpio_port_c, 14, TRIS_INPUT, LAT_LOW, ODC_DISABLE, ANALOG_DISABLE);
    gpioPinSetup(gpio_port_c, 15, TRIS_OUTPUT, LAT_LOW, ODC_DISABLE, ANALOG_DISABLE);
    
}
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

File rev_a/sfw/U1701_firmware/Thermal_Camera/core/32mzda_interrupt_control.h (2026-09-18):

/* ************************************************************************** */
/** Interrupt Control APIs

  @Company
    Marquette Senior Design E44

  @File Name
    32mz_interrupt_control.h

  @Summary
    Easier interface for enabling and disabling interrupts, checking interrupt flags, etc
    on the PIC32MZ family
  
  @Description
    Describe the purpose of this file.
 */
/* ************************************************************************** */

#ifndef _32MZDA_INTERRUPT_CONTROL_H    /* Guard against multiple inclusion */
#define _32MZDA_INTERRUPT_CONTROL_H

#include <xc.h>
#include <stdbool.h>

#include "sys/attribs.h"

// This typdef describes all of the interrupt sources available on the 32MZ EF family
typedef enum {

  core_timer_interrupt                  = 0,
  core_software_interrupt_0             = 1,
  core_software_interrupt_1             = 2,
  external_interrupt_0                  = 3,
  timer1                                = 4,
  input_capture_1_error                 = 5,
  input_capture_1                       = 6,
  output_compare_1                      = 7,
  external_interrupt_1                  = 8,
  timer2                                = 9,
  input_capture_2_error                 = 10,
  input_capture_2                       = 11,
  output_compare_2                      = 12,
  external_interrupt_2                  = 13,
  timer3                                = 14,
  input_capture_3_error                 = 15,
  input_capture_3                       = 16,
  output_compare_3                      = 17,
  external_interrupt_3                  = 18,
  timer4                                = 19,
  input_capture_4_error                 = 20,
  input_capture_4                       = 21,
  output_compare_4                      = 22,
  external_interrupt_4                  = 23,
  timer5                                = 24,
  input_capture_5_error                 = 25,
  input_capture_5                       = 26,
  output_compare_5                      = 27,
  timer6                                = 28,
  input_capture_6_error                 = 29,
  input_capture_6                       = 30,
  output_compare_6                      = 31,
  timer7                                = 32,
  input_capture_7_error                 = 33,
  input_capture_7                       = 34,
  output_compare_7                      = 35,
  timer8                                = 36,
  input_capture_8_error                 = 37,
  input_capture_8                       = 38,
  output_compare_8                      = 39,
  timer9                                = 40,
  input_capture_9_error                 = 41,
  input_capture_9                       = 42,
  output_compare_9                      = 43,
  adc_global_interrupt                  = 44,
  adc_fifo_interrupt                    = 45,
  adc_digital_comparator_1              = 46,
  adc_digital_comparator_2              = 47,
  adc_digital_comparator_3              = 48,
  adc_digital_comparator_4              = 49,
  adc_digital_comparator_5              = 50,
  adc_digital_comparator_6              = 51,
  adc_digital_filter_1                  = 52,
  adc_digital_filter_2                  = 53,
  adc_digital_filter_3                  = 54,
  adc_digital_filter_4                  = 55,
  adc_digital_filter_5                  = 56,
  adc_digital_filter_6                  = 57,
  adc_fault                             = 58,
  adc_data_0                            = 59,
  adc_data_1                            = 60,
  adc_data_2                            = 61,
  adc_data_3                            = 62,
  adc_data_4                            = 63,
  adc_data_5                            = 64,
  adc_data_6                            = 65,
  adc_data_7                            = 66,
  adc_data_8                            = 67,
  adc_data_9                            = 68,
  adc_data_10                           = 69,
  adc_data_11                           = 70,
  adc_data_12                           = 71,
  adc_data_13                           = 72,
  adc_data_14                           = 73,
  adc_data_15                           = 74,
  adc_data_16                           = 75,
  adc_data_17                           = 76,
  adc_data_18                           = 77,
  adc_data_19                           = 78,
  adc_data_20                           = 79,
  adc_data_21                           = 80,
  adc_data_22                           = 81,
  adc_data_23                           = 82,
  adc_data_24                           = 83,
  adc_data_25                           = 84,
  adc_data_26                           = 85,
  adc_data_27                           = 86,
  adc_data_28                           = 87,
  adc_data_29                           = 88,
  adc_data_30                           = 89,
  adc_data_31                           = 90,
  adc_data_32                           = 91,
  adc_data_33                           = 92,
  adc_data_34                           = 93,
  adc_data_35                           = 94,
  adc_data_36                           = 95,
  adc_data_37                           = 96,
  adc_data_38                           = 97,
  adc_data_39                           = 98,
  adc_data_40                           = 99,
  adc_data_41                           = 100,
  adc_data_42                           = 101,
  adc_data_43                           = 102,
  usb_suspend_resume_event              = 103,
  core_performance_counter_interrupt    = 104,
  core_fast_debug_channel_interrupt     = 105,
  system_bus_protection_violation       = 106,
  crypto_engine_event                   = 107,
  spi1_fault                            = 109,
  spi1_receive_done                     = 110,
  spi1_transfer_done                    = 111,
  uart1_fault                           = 112,
  uart1_receive_done                    = 113,
  uart1_transfer_done                   = 114,
  i2c1_bus_collision_event              = 115,
  i2c1_client_event                     = 116,
  i2c1_host_event                       = 117,
  porta_input_change_interrupt          = 118,
  portb_input_change_interrupt          = 119,
  portc_input_change_interrupt          = 120,
  portd_input_change_interrupt          = 121,
  porte_input_change_interrupt          = 122,
  portf_input_change_interrupt          = 123,
  portg_input_change_interrupt          = 124,
  porth_input_change_interrupt          = 125,
  portj_input_change_interrupt          = 126,
  portk_input_change_interrupt          = 127,
  pmp                                   = 128,
  pmp_error                             = 129,
  comparator_1_interrupt                = 130,
  comparator_2_interrupt                = 131,
  usb_general_event                     = 132,
  usb_dma_event                         = 133,
  dma_channel_0                         = 134,
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

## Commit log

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2023-11-11 copied lots of circuitry to reuse
    [Battery_Management.kicad_sch, Elapsed_Time_Counter.kicad_sch, External_Storage.kicad_sch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]
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2023-11-12 added PIC32MZ DA pinout spreadsheet
    [pinout_updated.xlsx]
2023-11-12 finished PIC32MZ DA symbol
    [PIC32MZ_DA_1.kicad_sch, PIC32MZ_DA_2.kicad_sch, PIC32MZ_DA_Power.kicad_sch]
2023-11-13 added lepton sensor, made some other schematic progress
    [Battery_Management.kicad_sch, Elapsed_Time_Counter.kicad_sch, External_Storage.kicad_sch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]
2023-11-14 changed USB HS port to hub
    [Thermal_Camera.kicad_sch, USB_HS_Port.kicad_sch, USB_Hub.kicad_sch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]
2023-11-14 added many more blank schematic sheets
    [Battery_Management.kicad_sch, Elapsed_Time_Counter.kicad_sch, External_Storage.kicad_sch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]
2023-11-14 added FLIR leptson IO level shifters
    [FLIR_Lepton_Sensor.kicad_sch, LCD_Backlight_Power_Supply.kicad_sch, LCD_Backlight_Telemetry.kicad_sch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]
2023-11-15 added SPI Flash and SD Card
    [External_Storage.kicad_sch]
2023-11-16 added some power supplies
    [External_Storage.kicad_sch, PIC32MZ_DA_Programming.kicad_sch, POS12_Input.kicad_sch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]
2023-11-16 fixed SOSC pin connection
    [PIC32MZ_DA_1.kicad_sch]
2023-11-18 changed a lot of circuits from +3.3V to +3.0V VDD
    [Elapsed_Time_Counter.kicad_sch, External_Storage.kicad_sch, FLIR_Lepton_Sensor.kicad_sch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]
2023-11-19 added new telemetry circuits
    [POS12_Input.kicad_sch, POS12_Telemetry.kicad_sch, POS1P2_Power_Supply.kicad_sch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]
2023-11-20 duplicated telemetry for all rails, added random tweaks to logic levels of signals
    [External_Storage.kicad_sch, LCD_Backlight_Telemetry.kicad_sch, POS12_Input.kicad_sch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]
2023-12-01 generated battery charger symbol
    [pinout.xlsx]
2023-12-01 added battery circuitry, LCD backlight
    [Battery_Management.kicad_sch, External_Storage.kicad_sch, FLIR_Lepton_Sensor.kicad_sch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]
2023-12-05 added PIC32 bypass, SD card load switch, other random junk
    [Battery_Management.kicad_sch, External_Storage.kicad_sch, FLIR_Lepton_Sensor.kicad_sch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]
2023-12-06 added some USB stuff
    [FLIR_Lepton_Sensor.kicad_sch, PIC32MZ_DA_1.kicad_sch, PIC32MZ_DA_2.kicad_sch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]
2023-12-06 added some more USB stuff
    [Battery_Management.kicad_sch, Elapsed_Time_Counter.kicad_sch, External_Storage.kicad_sch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]
2023-12-07 added some LCD components
    [FLIR_Lepton_Sensor.kicad_sch, Graphic_LCD.kicad_sch, LCD_Backlight_Power_Supply.kicad_sch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]
2023-12-07 added pull resistors for LCD signals
    [FLIR_Lepton_Sensor.kicad_sch, Graphic_LCD.kicad_sch, LCD_Backlight_Power_Supply.kicad_sch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]
2023-12-07 changed LED backlight driver
    [LCD_Backlight_Power_Supply.kicad_sch]
2023-12-07 chose backlight boost inductor
    [Battery_Management.kicad_sch, Elapsed_Time_Counter.kicad_sch, External_Storage.kicad_sch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]
2023-12-07 added notes for battery
    [Battery_Management.kicad_sch, FLIR_Lepton_Sensor.kicad_sch, PIC32MZ_DA_1.kicad_sch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]
2023-12-08 Added battery cell and protection IC
    [Battery_Management.kicad_sch, FLIR_Lepton_Sensor.kicad_sch, PIC32MZ_DA_1.kicad_sch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]
2024-03-29 lots of random schematic progress
    [Elapsed_Time_Counter.kicad_sch, External_Storage.kicad_sch, FLIR_Lepton_Sensor.kicad_sch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]
2024-03-29 assigned some GPIO pins
    [External_Storage.kicad_sch, FLIR_Lepton_Sensor.kicad_sch, PIC32MZ_DA_1.kicad_sch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]
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2024-04-02 worked on some battery stuff
    [Battery_Management.kicad_sch, PGOOD_LEDs.kicad_sch]
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2024-05-25 lots of schematic progress
    [Battery_Management.kicad_sch, Capacitive_Touch.kicad_sch, Elapsed_Time_Counter.kicad_sch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]
2024-05-25 assigned a ton of footprints
    [Battery_Management.kicad_sch, Capacitive_Touch.kicad_sch, Elapsed_Time_Counter.kicad_sch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]
2024-05-25 assigned some part numbers
    [Battery_Management.kicad_sch, Capacitive_Touch.kicad_sch, Elapsed_Time_Counter.kicad_sch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]
2024-05-25 assigned resistor part numbers
    [Battery_Management.kicad_sch, Capacitive_Touch.kicad_sch, External_Storage.kicad_sch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]
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2024-05-25 started arranging some parts
    [Thermal_Camera.kicad_pcb]
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2024-07-12 started placing a lot more components in PCB layout
    [Thermal_Camera.kicad_pcb]
2024-07-12 more PCB component placement
    [Thermal_Camera.kicad_pcb]
2024-07-16 lots of PCB placement progress
    [Battery_Management.kicad_sch, External_Storage.kicad_sch, Thermal_Camera.kicad_pcb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]
2024-07-19 fixed LCD ribbon cable pinout, added footprint
    [Graphic_LCD.kicad_sch, Thermal_Camera.kicad_pcb]
2024-08-15 generated rough LCD outline, made board outline
    [Graphic_LCD.kicad_sch, Thermal_Camera.kicad_pcb]
2024-08-15 placed input power circuit
    [Thermal_Camera.kicad_pcb]
2024-08-15 placed battery charger circuitry
    [Thermal_Camera.kicad_pcb]
2024-08-15 placed some power supplies
    [Thermal_Camera.kicad_pcb]
2024-08-15 placed more power supplies
    [Thermal_Camera.kicad_pcb]
2024-08-15 placed LCD backlight driver
    [Thermal_Camera.kicad_pcb]
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2024-08-19 a ton of routing progress, power planes, ehat have you
    [POS1P2_Power_Supply.kicad_sch]
2024-09-05 some more routing, moved some misc nets on MCU
    [Battery_Management.kicad_sch, Capacitive_Touch.kicad_sch, Elapsed_Time_Counter.kicad_sch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]
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2024-11-13 fixed heartbeat timer period
    [heartbeat_timer.c, main.c]
2024-11-14 fixed heartbeat timer period, again
    [heartbeat_timer.c, pin_macros.h]
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2024-12-12 got cause of reset working
    [main.c]
2024-12-12 attemping to fix serial receive
    [main.c, pic32mzda_gpio_setup.c]
2026-07-03 fixed UART bug
2026-07-04 added rtcc, missing PMD stuff
    [main.c, power_saving.c]
2026-07-04 fix heartbeat status omissions
    [heartbeat_timer.c]
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2026-07-05 fixed I2C print status definition
2026-07-05 added HLVD code, updated cause of reset, updated github CI
    [main.c]
2026-07-05 fix some error handler code, update github CI job
    [error_handler.c]
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2026-07-05 fixed USB UART RX bug
    [power_saving.c]
2026-07-06 fix some DDR2 things, add more printout verbosity
    [main.c]
2026-07-10 fixed I2C PMD bug
    [power_saving.c]
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2026-07-11 clarified USB UART error handler flag names
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2026-07-12 Add refdes to I2C device error flags, set during init fail or fail to read/write
    [error_handler.c, i2c_devices.c, main.c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]
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2026-07-12 Switch telemetry print flag to non-persistent to keep from continuing after a reset
    [main.c]
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2026-07-16 MAssive project restructure, atempting to restart in vscode natively rather than a conversion. SDHC fixes
    [PIC32_OSC_CONFIG_v1.1.xlsx]
2026-07-18 adding other stuff i missed
    [pic32mzda_gpio_setup.c]
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2026-07-18 got sdcard hot swapping working
    [main.c, sdhc.c]
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2026-07-22 Rework live telemetry printout to not lag
    [battery_monitor.c, heartbeat_services.c, main.c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]
2026-07-23 battery fuel gauge bug fixes, now seems to be working
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2026-07-29 Some FLIR bug fixes
    [flir.c]
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2026-07-31 flex PCB layout
    [CTP_interposer.kicad_pcb]
2026-07-31 finished CTP flex PCB
    [CTP_interposer-B_Cu.gbr, CTP_interposer-B_Mask.gbr, CTP_interposer-B_Paste.gbr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]
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2026-08-01 Add flir error screen
    [main.c]
2026-08-01 fix the SD card/FLIR video boot conflict
    [flir.c, main.c, sdhc.c]
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2026-08-08 fixed connector orientation and pinout
    [CTP_interposer-B_Cu.gbr, CTP_interposer-B_Mask.gbr, CTP_interposer-B_Paste.gbr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]
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2026-09-13 fix USB UART receive bug on boot, where it was missing the first command
2026-09-13 fix low batt signal polarity
    [battery_monitor.c]
